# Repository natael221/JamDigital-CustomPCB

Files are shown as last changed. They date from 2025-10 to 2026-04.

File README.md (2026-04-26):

# 🕋 Custom Digital Clock PCB (ESP32 + Arduino Nano)

> A fully integrated, custom PCB redesign of the **Jakarta Dishub Digital Clock**, engineered to eliminate messy jumper wires and deliver a robust, production-ready hardware solution. ⚡

---

## 📸 Hardware Preview

| 📐 Schematic Design | 🖨️ PCB Routing (2D) |
| :---: | :---: |
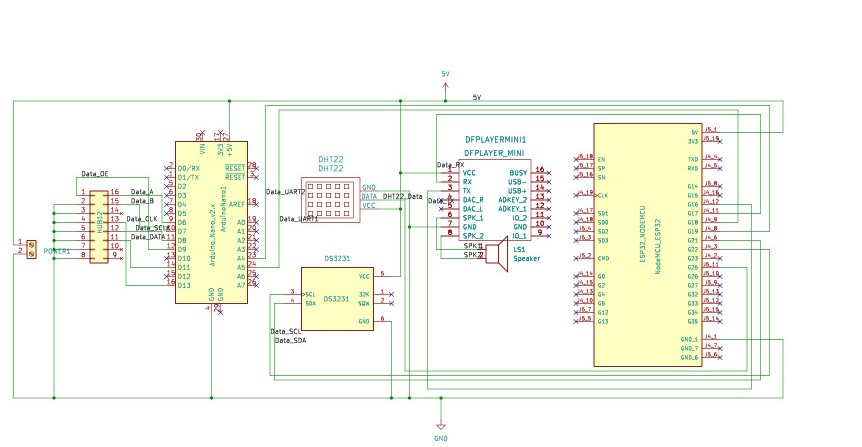
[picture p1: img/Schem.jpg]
Schematic
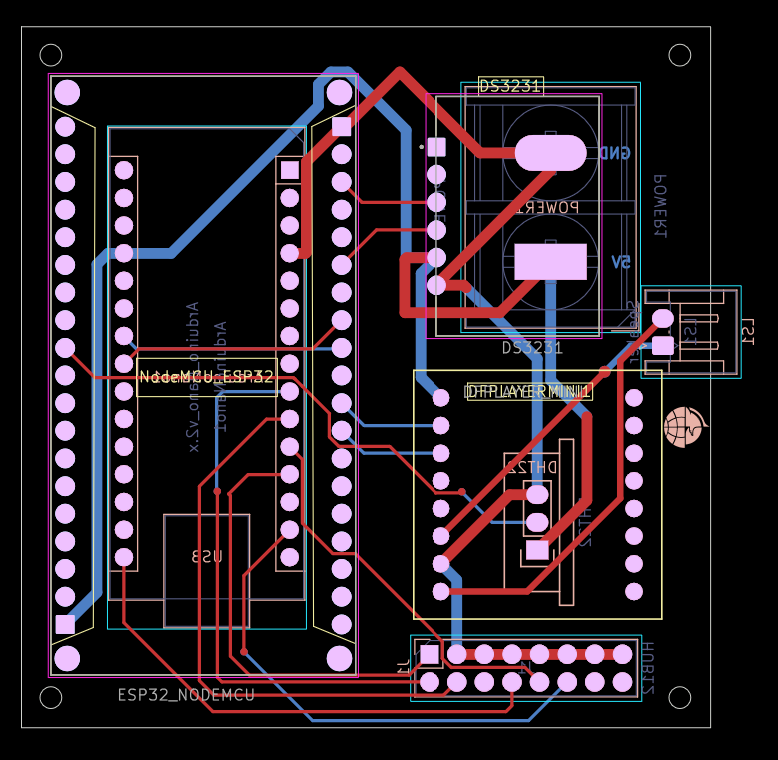
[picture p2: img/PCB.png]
PCB Layout
|  |  |

| 🧊 3D View (Front) | 🧊 3D View (Back) |
| :---: | :---: |
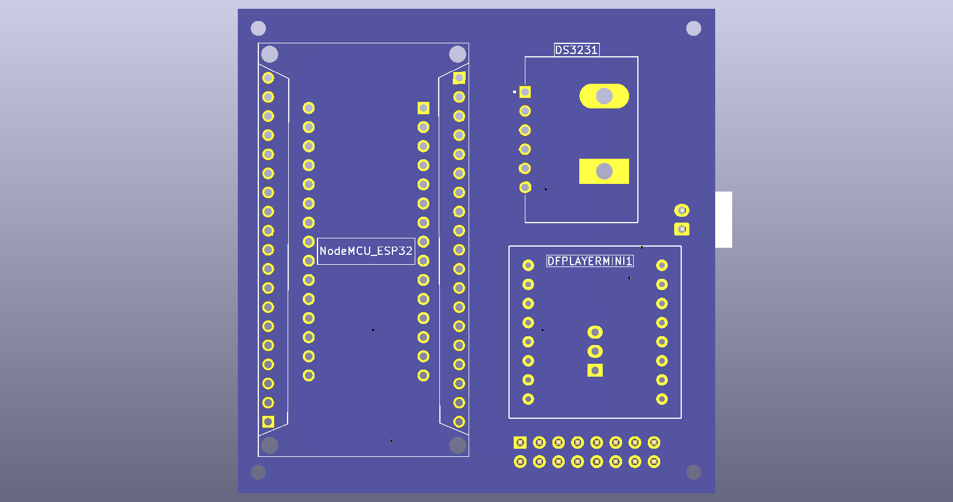
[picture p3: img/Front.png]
3D Front
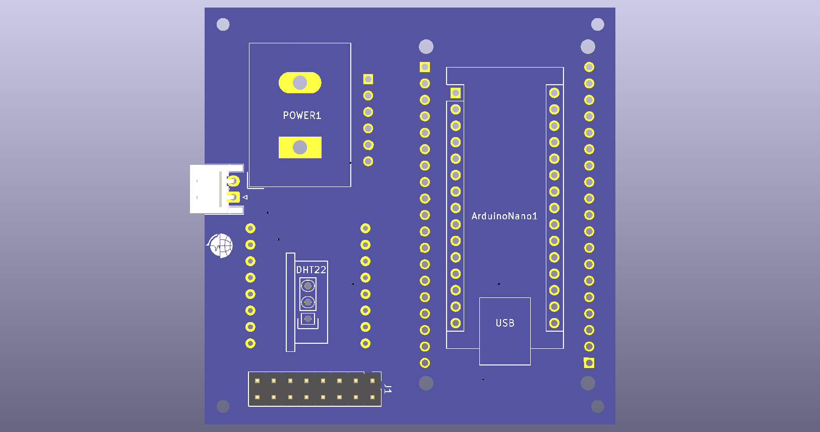
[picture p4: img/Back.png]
3D Back
|  |  |

---

## 💡 Overview

This system goes beyond a simple clock. It acts as a real-time information hub displaying **time, date, temperature, humidity, and dynamic motivational quotes** on a **P10 LED Panel**. 

To make it fully autonomous, it features **automatic Adzan audio playback** triggered at specific times via a DFPlayer Mini, all manageable through a **Wi-Fi-based web interface** 🌐.

### 🧠 Dual-Microcontroller Architecture
To handle high-speed display multiplexing without compromising IoT capabilities, the workload is split:
* **ESP32** → The "Brain" handling Wi-Fi, Web Server, sensor polling, and audio logic.
* **Arduino Nano** → The "Display Driver" dedicated entirely to driving the P10 HUB12 panel via I²C commands from the ESP32.

---

## ⚙️ Core Features

* 🕐 **Precision Timekeeping:** Driven by the highly accurate DS3231 RTC module.
* 🌡️ **Environment Monitoring:** Real-time data processing from the DHT22 sensor.
* 🔊 **Automated Audio:** DFPlayer Mini seamlessly plays MP3 files from an SD card.
* 💬 **Dynamic Quotes API:** Fetches and displays daily motivation.
* 🌐 **Local Web Interface:** Easy configuration of settings without hardcoding.
* 🔌 **Custom PCB Design:** Two-layer board integrating all modules flawlessly.

---

## 🎓 The PCB Design Journey

This repository marks my **first dive into designing a PCB from scratch using KiCad 10.0.1**. 

Instead of just wiring modules together, I took the time to understand:
* **Schematic flow and logical groupings.**
* **Netclass configurations** for handling power vs. data lines.
* **Trace routing** with wider tracks for power stability.
* **ERC/DRC validation** to ensure a safe, short-circuit-free design.

> 🎯 *Takeaway: This wasn't just about building a clock; it was a hands-on masterclass in bridging the gap between a messy breadboard prototype and a professional hardware product.*

Check out the original breadboard prototype here: 👉 [Jakarta Dishub Digital Clock v1](https://github.com/natael221/JAMDIGITALPUSDATINDISHUB)

---

## 🧰 Bill of Materials (BOM) Highlights

| Component | Role in the System |
| :--- | :--- |
| **ESP32 Dev Board** | Main IoT Controller |
| **Arduino Nano** | HUB12 Display Controller |
| **P10 LED Panel** | Main Visual Display |
| **DHT22** | Temp & Humidity Sensor |
| **DS3231 RTC** | Real-Time Clock |
| **DFPlayer Mini & Speaker** | Audio Subsystem |

---

## 🚀 Getting Started & Flashing Firmware

1. **Hardware Setup:** Connect both the ESP32 and Arduino Nano to your PC.
2. **Flash ESP32:** Compile and upload `main_esp32.ino` (Target: *ESP32 Dev Module*).
3. **Flash Nano:** Compile and upload `display_nano.ino` (Target: *Arduino Nano*, use Old Bootloader if necessary).
4. **Prepare Audio:** Load your Adzan `.mp3` files into the root/designated folder of a FAT32 formatted SD Card and insert it into the DFPlayer.
5. **Power Up:** Supply a stable **5V DC** to the board. The startup sequence will begin.
6. **Network Config:** Local IP address, connect via your browser, and start configuring! 🎉

---

## 👨‍💻 About the Developer

**Natanael Siwalette** *Embedded Systems | IoT | Hardware Enthusiast*

Currently looking for new opportunities! (Yes, officially unemployed 😢😭, but always building).

📫 **Connect with me:** [LinkedIn](https://www.linkedin.com/in/natanael-siwalette)  
💻 **Check out my work:** [Portfolio](https://natael221.github.io/)

---

## 📜 License

This project is open-source for **educational, research, and prototype development purposes**. Feel free to fork, modify, or use it as inspiration. Proper credit is always appreciated 🙌.

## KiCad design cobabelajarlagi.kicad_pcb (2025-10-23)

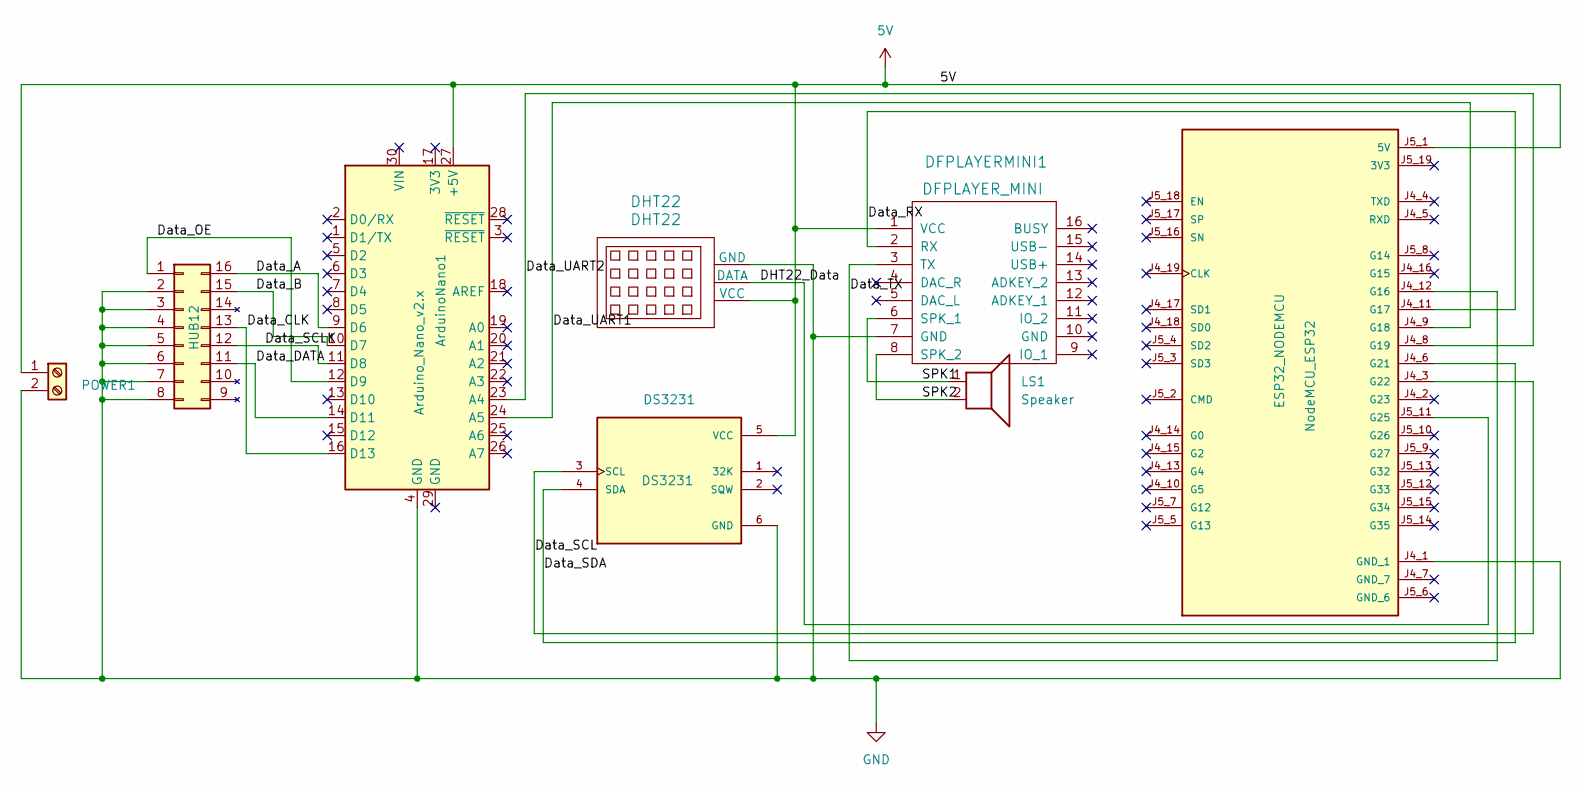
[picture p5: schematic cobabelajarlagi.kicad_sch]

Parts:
ArduinoNano1: Arduino_Nano_v2.x; Arduino_Nano
DFPLAYERMINI1: DFPLAYER_MINI; DFPlayer_V2
DHT22: DHT22; DHT11_Temperature_Humidity
DS3231: DS3231; MODULE_TC00500; PARTREV N/A
J1: HUB12; PinHeader_2x08_P2.54mm_Vertical
LS1: Speaker; JST_EH_S2B-EH_1x02_P2.50mm_Horizontal
NodeMCU_ESP32: ESP32_NODEMCU; MODULE_ESP32_NODEMCU
POWER1: POWER; TerminalBlock_Dinkle_DT-55-B01X-02_P10.00mm

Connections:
+5V: ArduinoNano1.27 (+5V), DFPLAYERMINI1.1 (VCC), DHT22.2 (VCC), DS3231.5 (VCC), NodeMCU_ESP32.J5_1 (5V), POWER1.1
/DHT22_Data: DHT22.1 (DATA), NodeMCU_ESP32.J5_11 (G25)
/Data_A: ArduinoNano1.9 (D6), J1.16 (A)
/Data_B: ArduinoNano1.10 (D7), J1.15 (B)
/Data_CLK: ArduinoNano1.16 (D13), J1.13 (CLK)
/Data_DATA: ArduinoNano1.14 (D11), J1.11 (Data)
/Data_OE: ArduinoNano1.12 (D9), J1.1
/Data_RX: DFPLAYERMINI1.2 (RX), NodeMCU_ESP32.J4_11 (G17)
/Data_SCL: DS3231.3 (SCL), NodeMCU_ESP32.J4_3 (G22)
/Data_SCLK: ArduinoNano1.11 (D8), J1.12 (SCLK)
/Data_SDA: DS3231.4 (SDA), NodeMCU_ESP32.J4_6 (G21)
/Data_TX: DFPLAYERMINI1.3 (TX), NodeMCU_ESP32.J4_12 (G16)
/Data_UART1: ArduinoNano1.24 (A5), NodeMCU_ESP32.J4_9 (G18)
/Data_UART2: ArduinoNano1.23 (A4), NodeMCU_ESP32.J4_8 (G19)
/SPK1: DFPLAYERMINI1.6 (SPK_1), LS1.1
/SPK2: DFPLAYERMINI1.8 (SPK_2), LS1.2
GND: ArduinoNano1.4 (GND), DFPLAYERMINI1.7 (GND), DHT22.3 (GND), DS3231.6 (GND), J1.2 (GND), J1.3 (GND), J1.4 (GND), J1.5 (GND), J1.6 (GND), J1.7 (GND), J1.8 (GND), NodeMCU_ESP32.J4_1 (GND_1), POWER1.2

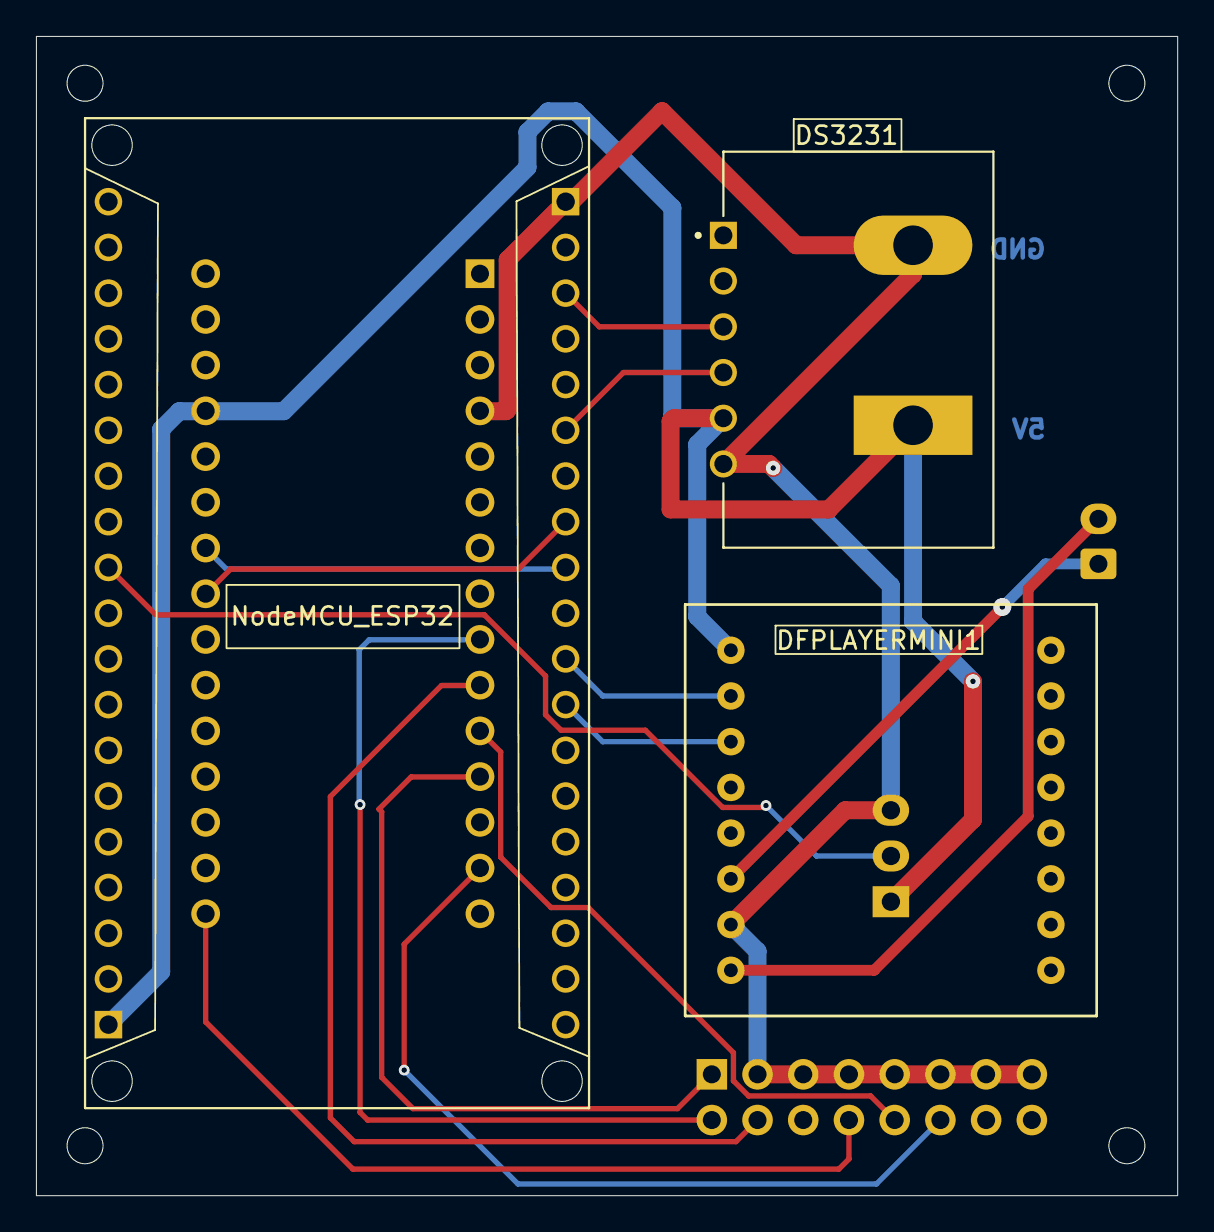
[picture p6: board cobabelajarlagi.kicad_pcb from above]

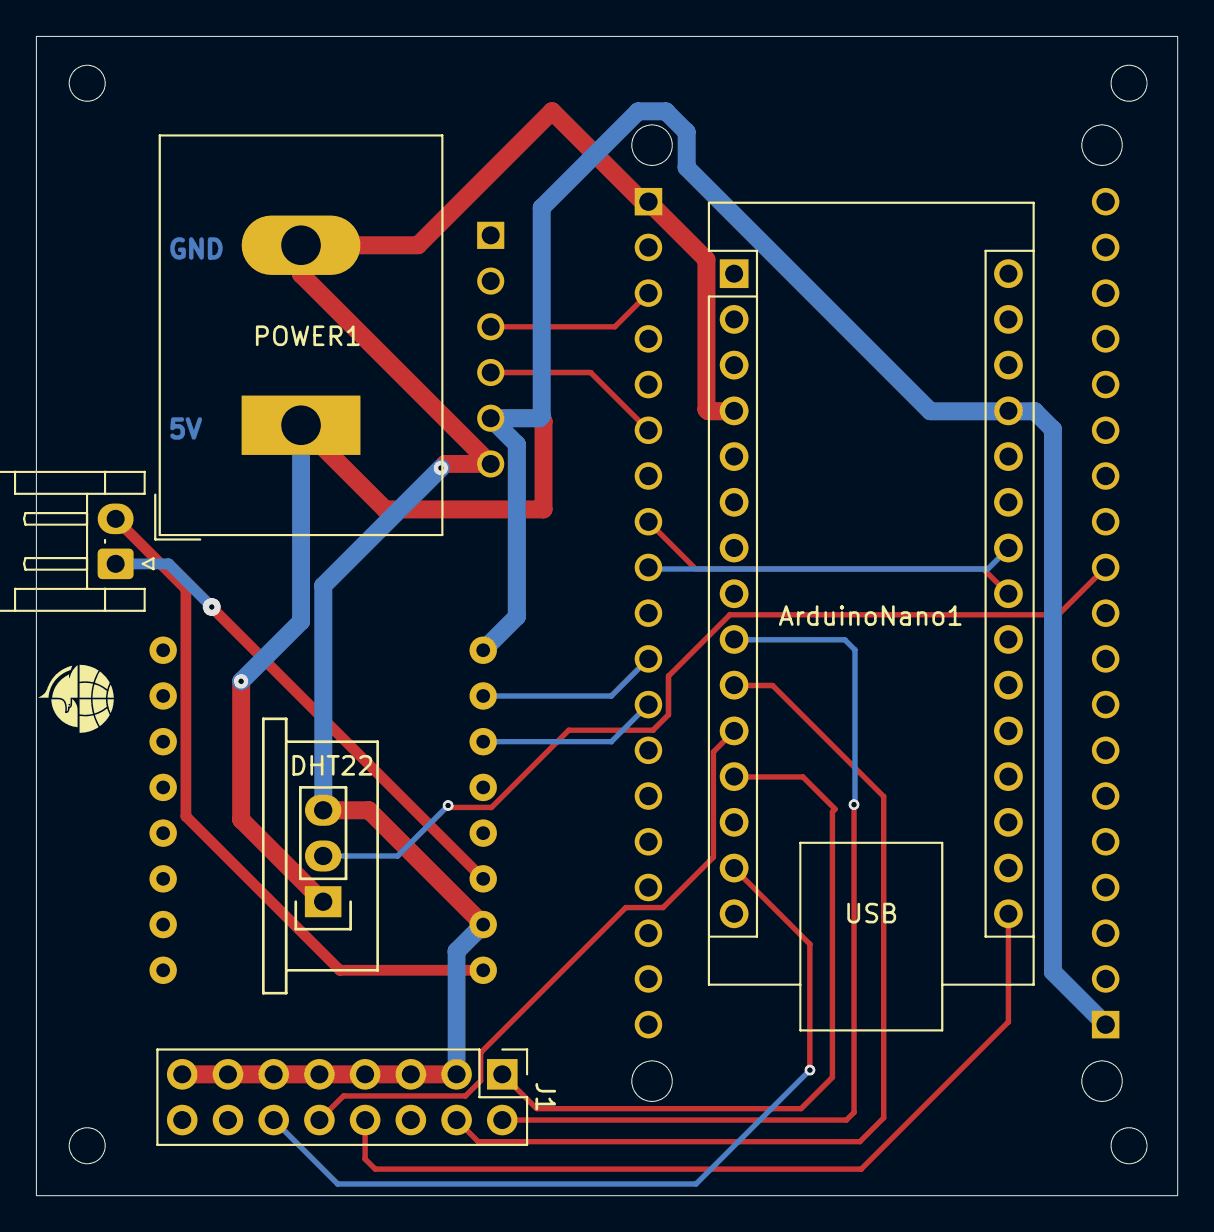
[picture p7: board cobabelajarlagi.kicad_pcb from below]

Board: 2 copper layers, 63.4 x 64.4 mm, 8 parts (5 on the bottom side), 17 nets.
